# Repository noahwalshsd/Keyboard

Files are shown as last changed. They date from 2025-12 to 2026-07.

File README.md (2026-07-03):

# Slim Shady Keyboard
My project is a 65% orthographic mecanical keyboard. It will be more ergonomic than a regular keyboard and mimic a laptop keyboard in its quietness and lack of push depth. 
I needed to get into PCBs. Before this project, I didn't even know what they were or even what PCB meant. I decided to make an ortholinear keyboardbecause I saw them being priced extremely high and I thought I could make it cheaper as my first PCB project. Because it is my first PCB project, I spent well over the suggested time in my learning efforts. I failed many times in nearly everything. I only got the CAD right first try. The cherry on top is that I may qualify for Prototype. 
There is 1 spacebar keycap, 1 3-wide keycap, 5 2-wide keycaps, and 60 small keycaps. 













BOM: You can find it at the BOM.csv tab






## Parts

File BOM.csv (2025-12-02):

Material | Cost per | Amount needed | Total Cost | Do I have? | HC funding | Link
PCB | $22.40 | 1 | $29.27 | No | $29.27 | https://cart.jlcpcb.com/shopcart/cart, Board: Y2-11347334A
RP Pico | $11.39 | 1 | $11.39 | No | $11.39 | https://www.amazon.com/GATERON-Silent-Keyboard-Switches-Mechanical/dp/B0CPXXRPSQ
PLA Filament | $14 | 1 | $14 | Yes | N/A | https://us.elegoo.com/collections/pla-filament/products/pla-filament-1-75mm-colored-1kg
Gateron KS-9 Switches (35 CT) | $20.15 | 2 | $40.30 | No | $40.30 | https://www.amazon.com/GATERON-Silent-Keyboard-Switches-Mechanical/dp/B0CPXXRPSQ
DO-35 Diodes (125 pc) | $5.99 | 1 | $5.99 | No | $5.99 | https://www.amazon.com/gp/product/B07Q4F3Y5W/ref=ox_sc_act_title_1?smid=A2RFXKS6GNXFWP&psc=1
Total |  |  | $100.95 |  | $86.95

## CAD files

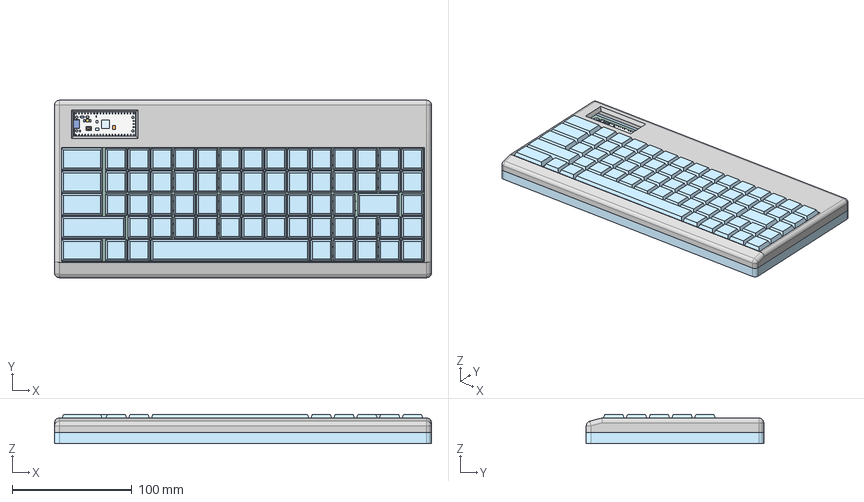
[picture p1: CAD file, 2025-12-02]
CAD.step
315.2 x 148.5 x 24.6 mm
KiCad 1_PCB
?�?__??__��_ x 132
MX? ?�LEDLEDLED x 330
MX ? ??����_���?_ _ x 66
MX �� ������_��_ __��1 x 66
MX�� ���� �ײ� �̡�2 __Ĭ��_��2____��_ x 66
PICO_REF_LED
PICO_REF_INDUCTOR
PICO_REF_COMP_3 x 2
PICO_REF_COMP_1
PICO_REF_COMP_5
PICO_REF_USB x 5
PICO_REF_COMP_6
PICO_REF_COMP_4
PICO_REF_SWITCH
PICO_REF_MICROCONTROLLER
PICO_REF_BOARD
PICO_REF_COMP_2
PICO_REF_COMP_7

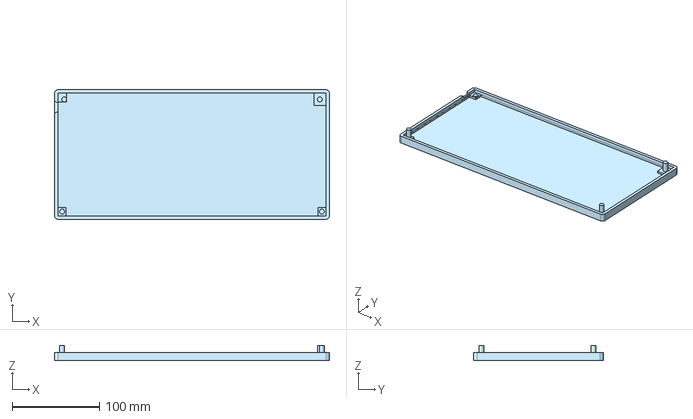
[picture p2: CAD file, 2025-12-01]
Production/CAD pieces/Bottom.step
315.2 x 148.5 x 17.3 mm

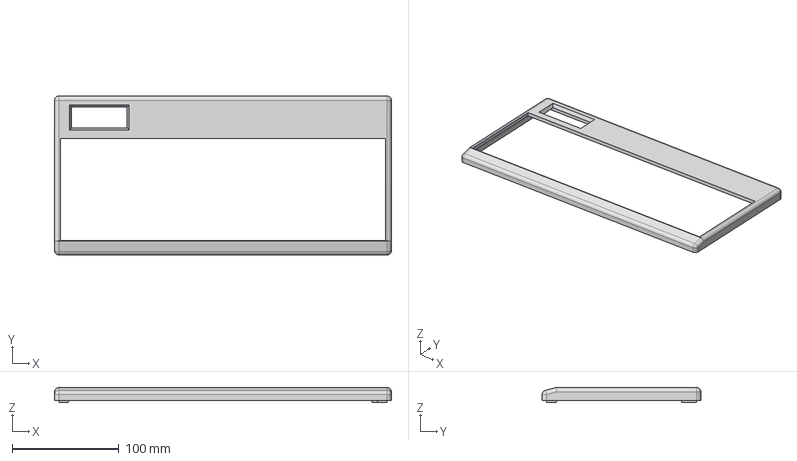
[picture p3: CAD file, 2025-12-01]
Production/CAD pieces/Top.step
315.2 x 148.5 x 14.0 mm

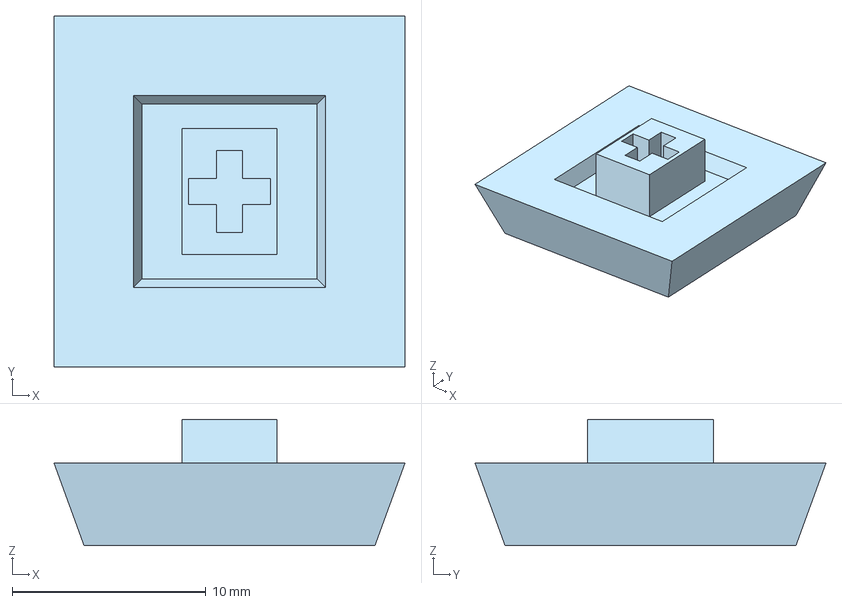
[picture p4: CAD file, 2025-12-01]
Production/CAD pieces/Common Keycap.step
18.1 x 18.1 x 6.50 mm

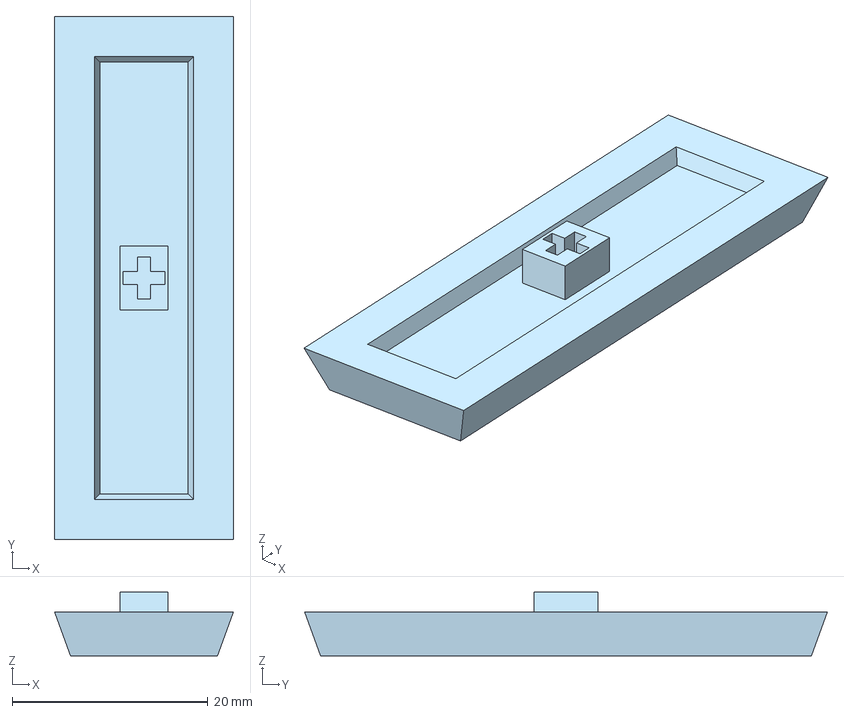
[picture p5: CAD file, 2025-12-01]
Production/CAD pieces/3-wide keyboard.step
18.3 x 53.4 x 6.50 mm

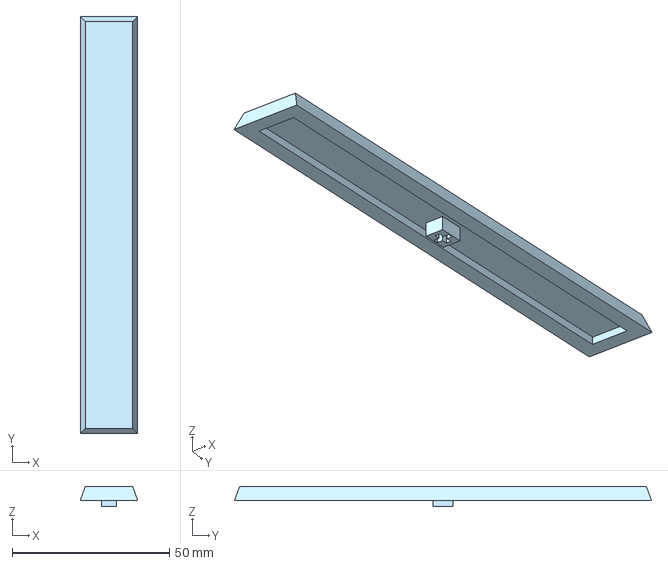
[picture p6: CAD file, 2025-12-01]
Production/CAD pieces/Spacebar keycap.step
18.3 x 132.6 x 6.50 mm

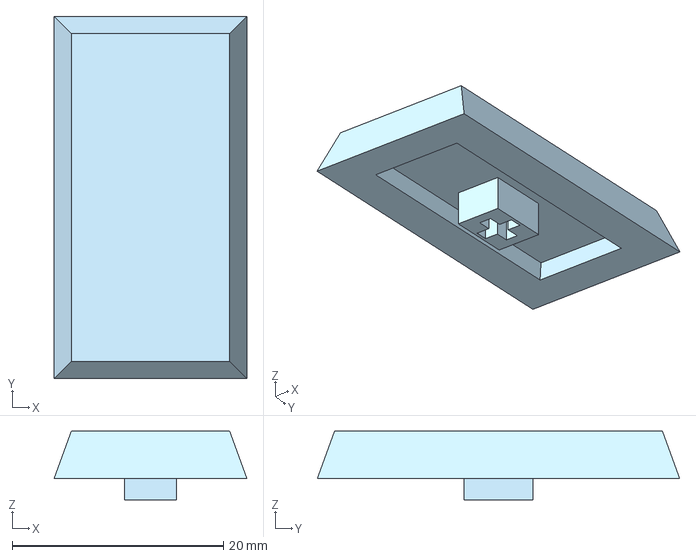
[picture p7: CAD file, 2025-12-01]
Production/CAD pieces/2 wide keycap.step
18.3 x 34.3 x 6.50 mm

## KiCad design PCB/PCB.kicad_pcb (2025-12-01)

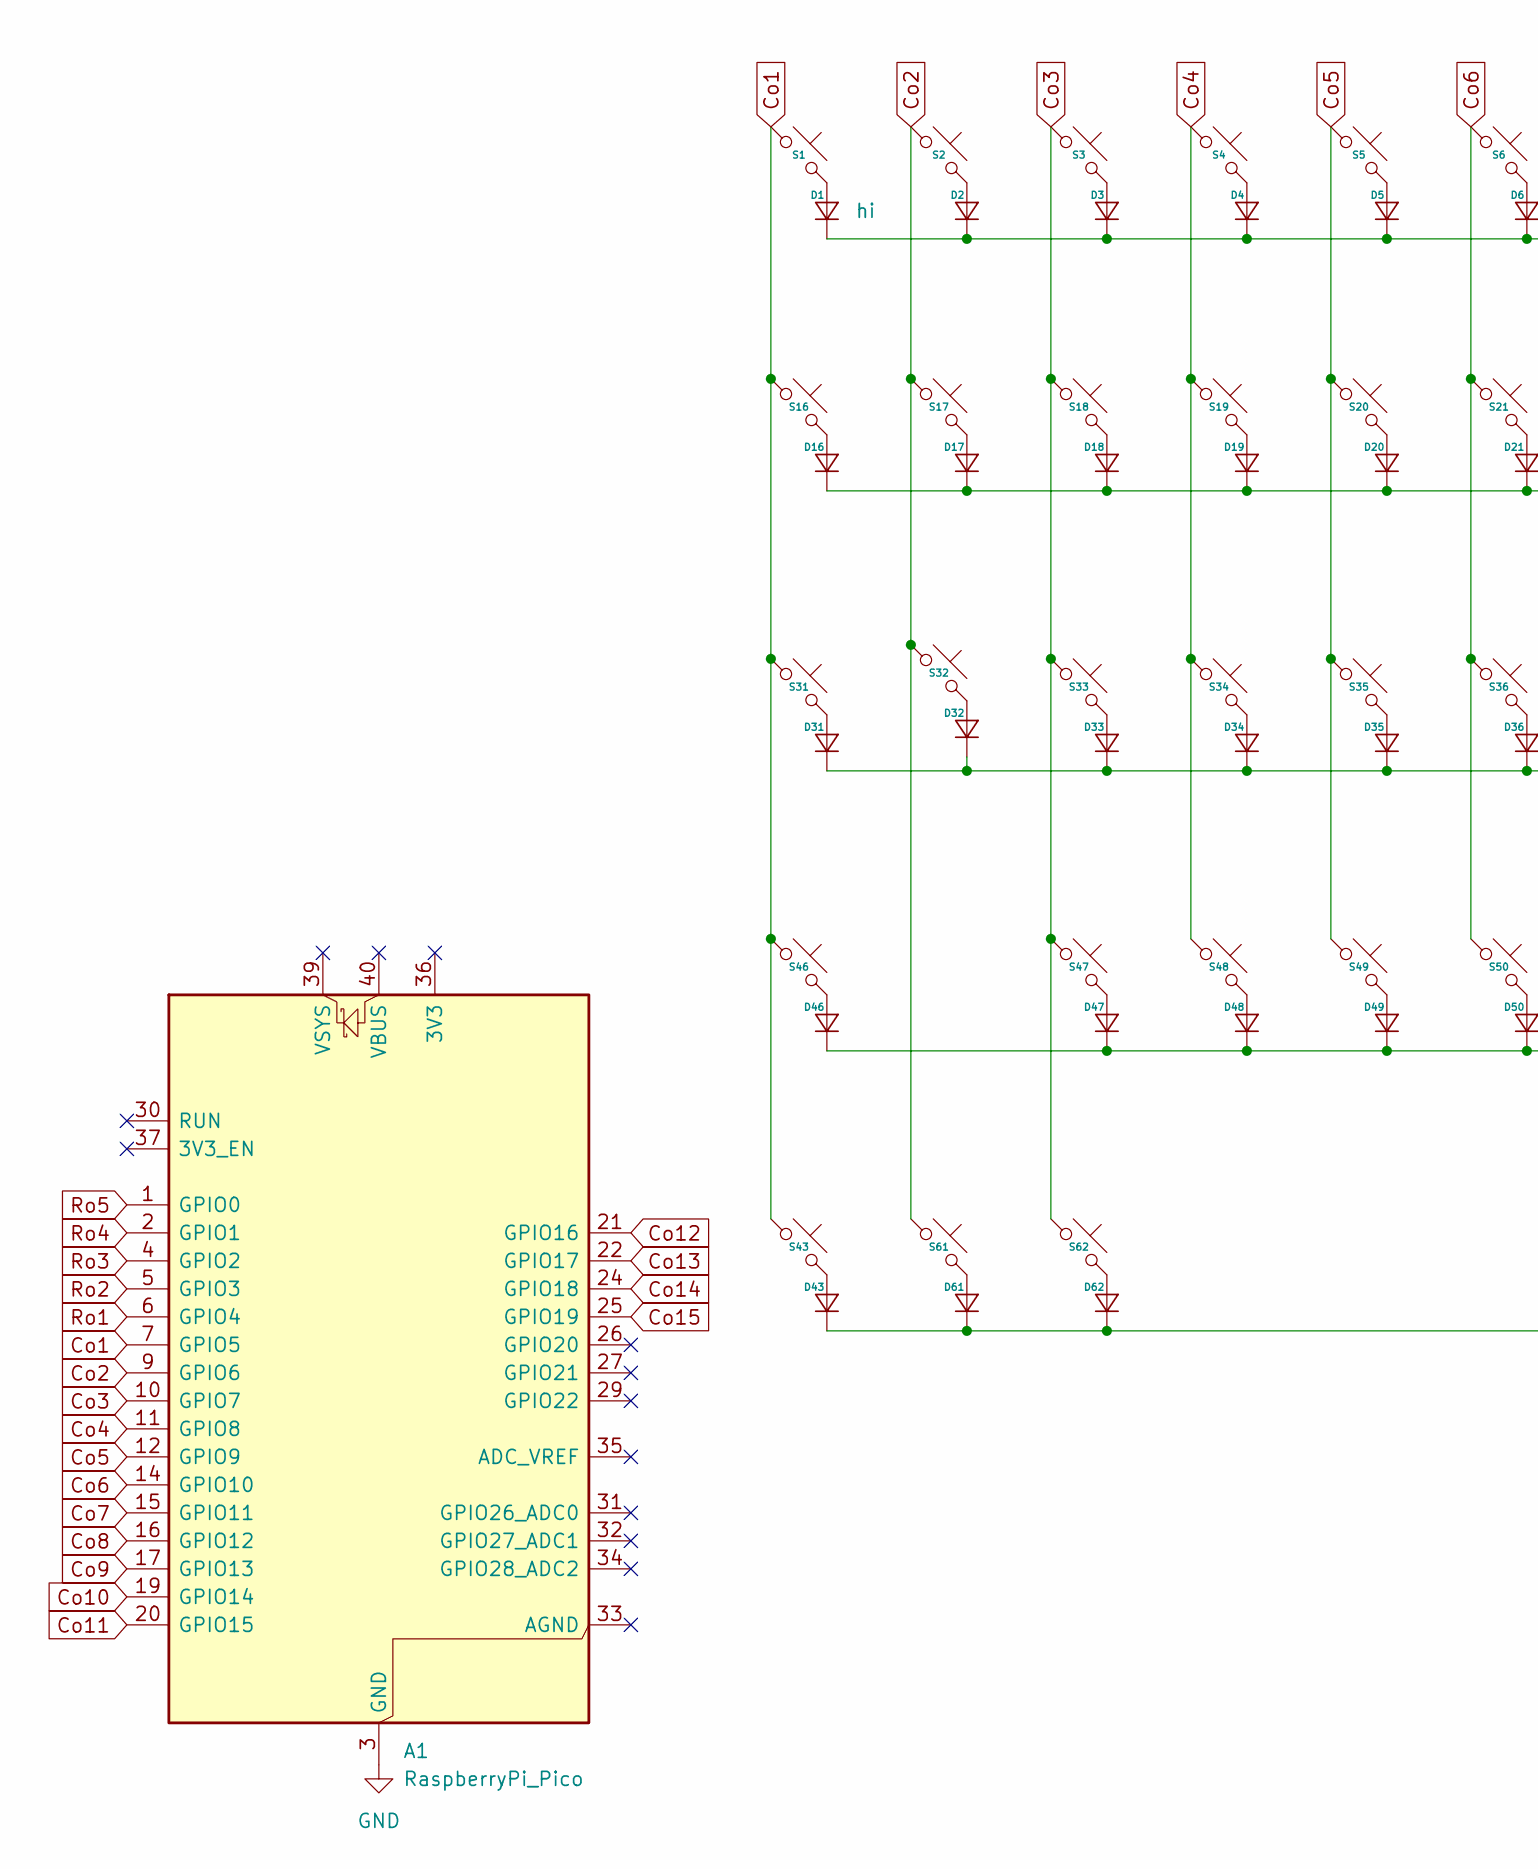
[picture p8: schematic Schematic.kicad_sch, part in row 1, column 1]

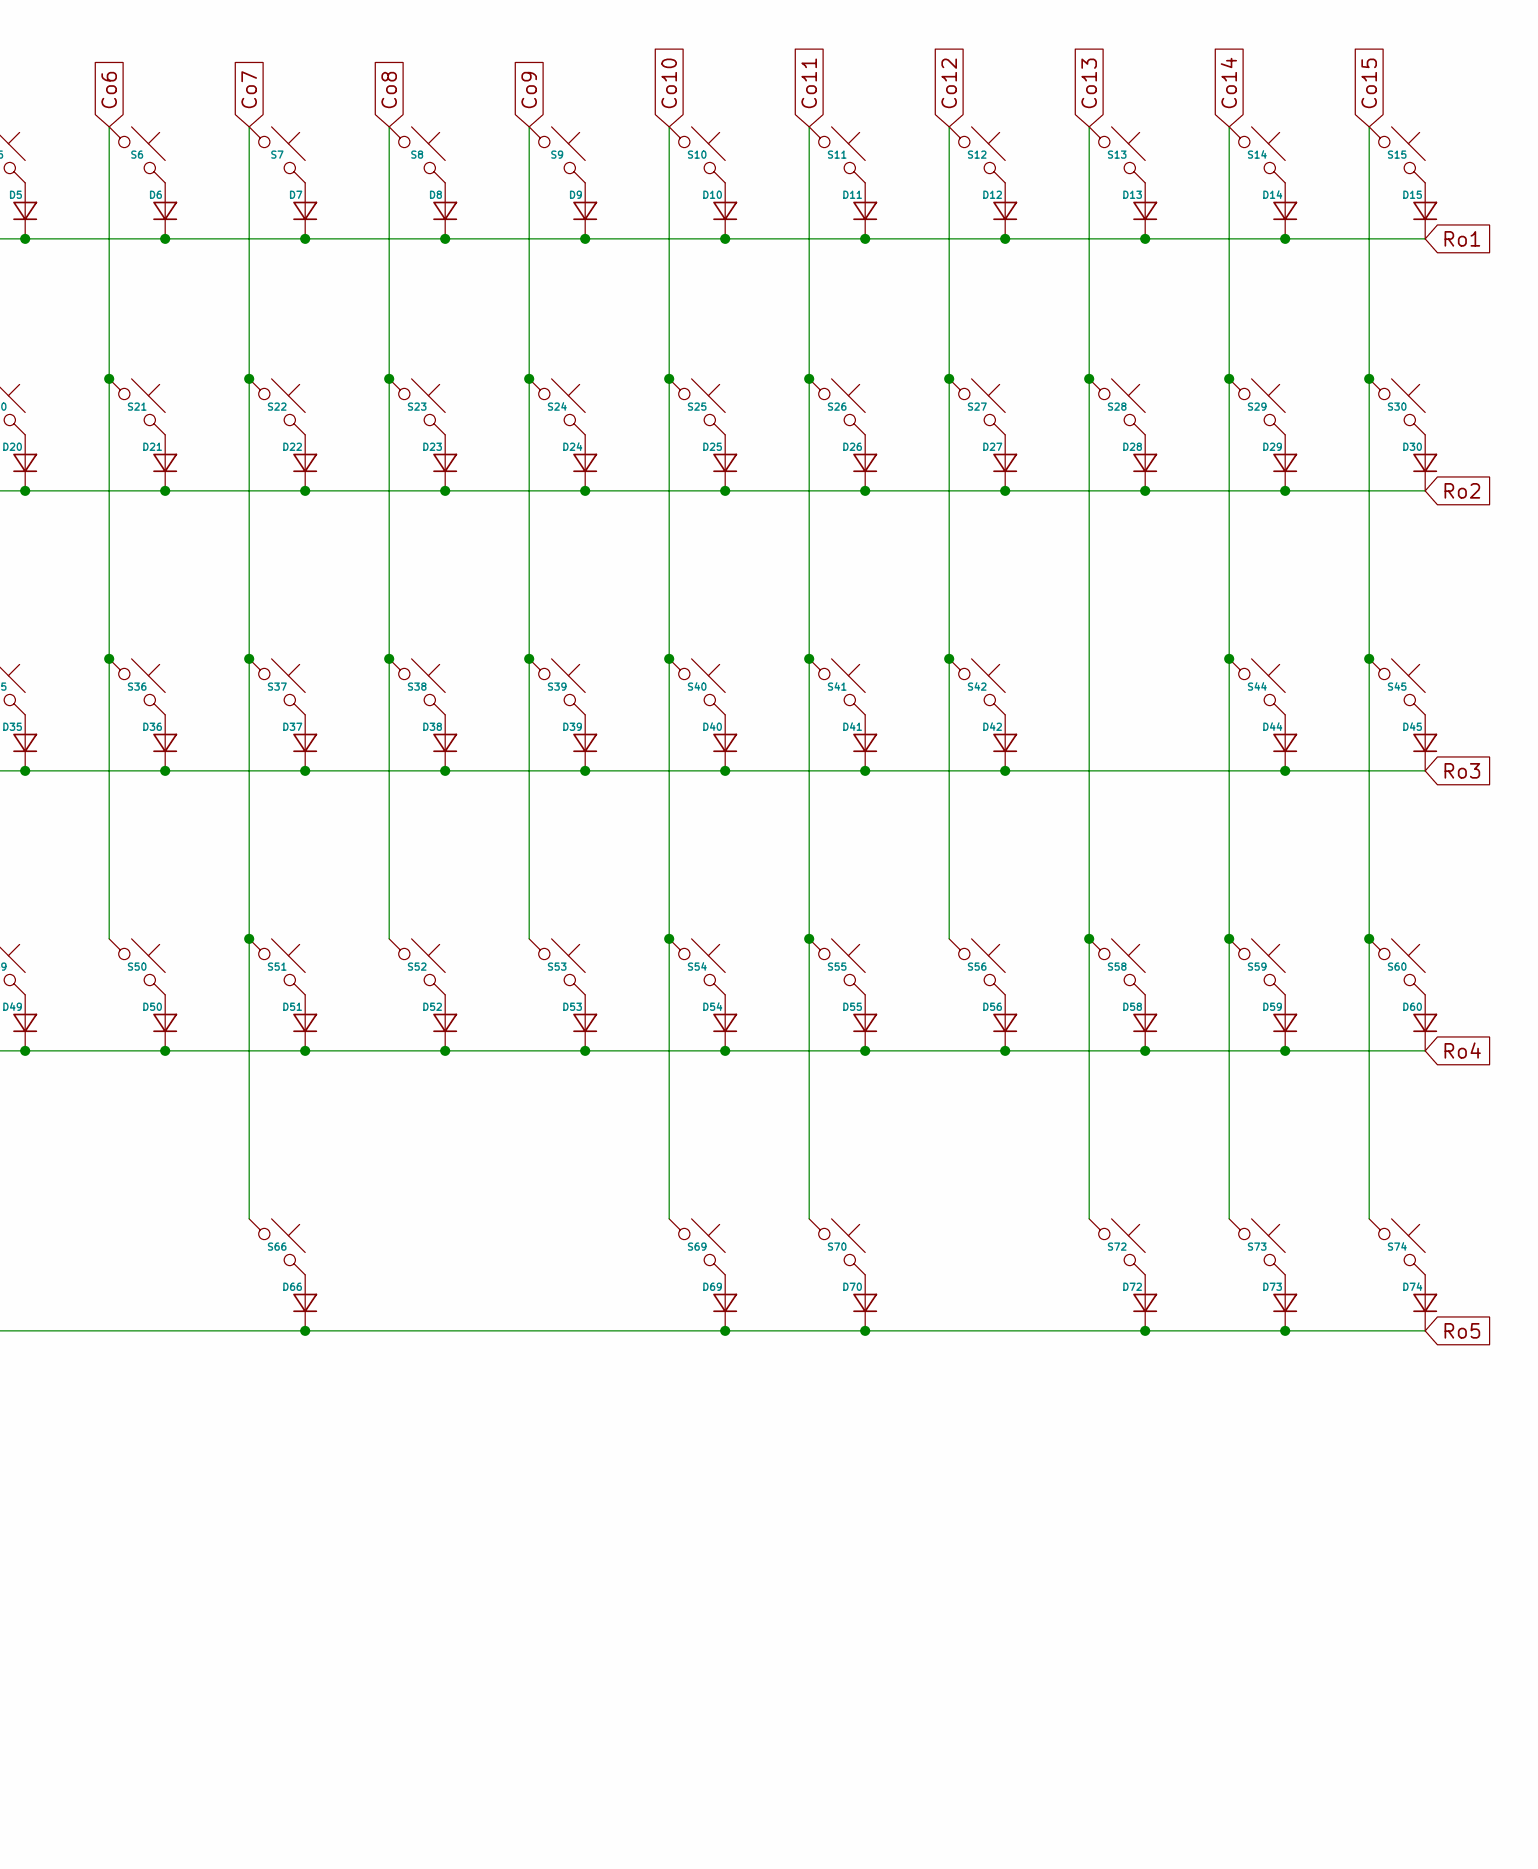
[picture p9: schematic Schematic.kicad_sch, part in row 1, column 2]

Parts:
A1: RaspberryPi_Pico; Raspberry_Pi_Pico
D1: hi; Diode_DO-35
D2, D3, D4, D5, D6, D7, D8, D9, D10, D11, D12, D13, D14, D15, D16, D17, D18, D19, D20, D21, D22, D23, D24, D25, D26, D27, D28, D29, D30, D31, D32, D33, D34, D35, D36, D37, D38, D39, D40, D41, D42, D43, D44, D45, D46, D47, D48, D49, D50, D51, D52, D53, D54, D55, D56, D58, D59, D60, D61, D62, D66, D69, D70, D72, D73, D74: Diode_DO-35
S1, S2, S3, S4, S5, S6, S7, S8, S9, S10, S11, S12, S13, S14, S15, S16, S17, S18, S19, S20, S21, S22, S23, S24, S25, S26, S27, S28, S29, S30, S31, S32, S33, S34, S35, S36, S37, S38, S39, S40, S41, S42, S43, S44, S45, S46, S47, S48, S49, S50, S51, S52, S53, S54, S55, S56, S58, S59, S60, S61, S62, S66, S69, S70, S72, S73, S74: MX_PCB_1.00u

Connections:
Co1: A1.7 (GPIO5), S1.1, S16.1, S31.1, S43.1, S46.1
Co2: A1.9 (GPIO6), S2.1, S17.1, S32.1, S61.1
Co3: A1.10 (GPIO7), S3.1, S18.1, S33.1, S47.1, S62.1
Co4: A1.11 (GPIO8), S4.1, S19.1, S34.1, S48.1
Co5: A1.12 (GPIO9), S5.1, S20.1, S35.1, S49.1
Co6: A1.14 (GPIO10), S6.1, S21.1, S36.1, S50.1
Co7: A1.15 (GPIO11), S7.1, S22.1, S37.1, S51.1, S66.1
Co8: A1.16 (GPIO12), S8.1, S23.1, S38.1, S52.1
Co9: A1.17 (GPIO13), S9.1, S24.1, S39.1, S53.1
Co10: A1.19 (GPIO14), S10.1, S25.1, S40.1, S54.1, S69.1
Co11: A1.20 (GPIO15), S11.1, S26.1, S41.1, S55.1, S70.1
Co12: A1.21 (GPIO16), S12.1, S27.1, S42.1, S56.1
Co13: A1.22 (GPIO17), S13.1, S28.1, S58.1, S72.1
Co14: A1.24 (GPIO18), S14.1, S29.1, S44.1, S59.1, S73.1
Co15: A1.25 (GPIO19), S15.1, S30.1, S45.1, S60.1, S74.1
GND: A1.3 (GND), A1.8 (GND), A1.13 (GND), A1.18 (GND), A1.23 (GND), A1.28 (GND), A1.38 (GND)
unnamed: D1.2 (A), S1.2
unnamed: D2.2 (A), S2.2
unnamed: D3.2 (A), S3.2
unnamed: D4.2 (A), S4.2
unnamed: D5.2 (A), S5.2
unnamed: D6.2 (A), S6.2
unnamed: D7.2 (A), S7.2
unnamed: D8.2 (A), S8.2
unnamed: D9.2 (A), S9.2
unnamed: D10.2 (A), S10.2
unnamed: D11.2 (A), S11.2
unnamed: D12.2 (A), S12.2
unnamed: D13.2 (A), S13.2
unnamed: D14.2 (A), S14.2
unnamed: D15.2 (A), S15.2
unnamed: D16.2 (A), S16.2
unnamed: D17.2 (A), S17.2
unnamed: D18.2 (A), S18.2
unnamed: D19.2 (A), S19.2
unnamed: D20.2 (A), S20.2
unnamed: D21.2 (A), S21.2
unnamed: D22.2 (A), S22.2
unnamed: D23.2 (A), S23.2
unnamed: D24.2 (A), S24.2
unnamed: D25.2 (A), S25.2
unnamed: D26.2 (A), S26.2
unnamed: D27.2 (A), S27.2
unnamed: D28.2 (A), S28.2
unnamed: D29.2 (A), S29.2
unnamed: D30.2 (A), S30.2
unnamed: D31.2 (A), S31.2
unnamed: D32.2 (A), S32.2
unnamed: D33.2 (A), S33.2
unnamed: D34.2 (A), S34.2
unnamed: D35.2 (A), S35.2
unnamed: D36.2 (A), S36.2
unnamed: D37.2 (A), S37.2
unnamed: D38.2 (A), S38.2
unnamed: D39.2 (A), S39.2
unnamed: D40.2 (A), S40.2
unnamed: D41.2 (A), S41.2
unnamed: D42.2 (A), S42.2
unnamed: D43.2 (A), S43.2
unnamed: D44.2 (A), S44.2
unnamed: D45.2 (A), S45.2
unnamed: D46.2 (A), S46.2
unnamed: D47.2 (A), S47.2
unnamed: D48.2 (A), S48.2
unnamed: D49.2 (A), S49.2
unnamed: D50.2 (A), S50.2
unnamed: D51.2 (A), S51.2
unnamed: D52.2 (A), S52.2
unnamed: D53.2 (A), S53.2
unnamed: D54.2 (A), S54.2
unnamed: D55.2 (A), S55.2
unnamed: D56.2 (A), S56.2
unnamed: D58.2 (A), S58.2
unnamed: D59.2 (A), S59.2
unnamed: D60.2 (A), S60.2
unnamed: D61.2 (A), S61.2
unnamed: D62.2 (A), S62.2
unnamed: D66.2 (A), S66.2
unnamed: D69.2 (A), S69.2
unnamed: D70.2 (A), S70.2
unnamed: D72.2 (A), S72.2
unnamed: D73.2 (A), S73.2
unnamed: D74.2 (A), S74.2
Ro1: A1.6 (GPIO4), D1.1 (K), D2.1 (K), D3.1 (K), D4.1 (K), D5.1 (K), D6.1 (K), D7.1 (K), D8.1 (K), D9.1 (K), D10.1 (K), D11.1 (K), D12.1 (K), D13.1 (K), D14.1 (K), D15.1 (K)
Ro2: A1.5 (GPIO3), D16.1 (K), D17.1 (K), D18.1 (K), D19.1 (K), D20.1 (K), D21.1 (K), D22.1 (K), D23.1 (K), D24.1 (K), D25.1 (K), D26.1 (K), D27.1 (K), D28.1 (K), D29.1 (K), D30.1 (K)
Ro3: A1.4 (GPIO2), D31.1 (K), D32.1 (K), D33.1 (K), D34.1 (K), D35.1 (K), D36.1 (K), D37.1 (K), D38.1 (K), D39.1 (K), D40.1 (K), D41.1 (K), D42.1 (K), D44.1 (K), D45.1 (K)
Ro4: A1.2 (GPIO1), D46.1 (K), D47.1 (K), D48.1 (K), D49.1 (K), D50.1 (K), D51.1 (K), D52.1 (K), D53.1 (K), D54.1 (K), D55.1 (K), D56.1 (K), D58.1 (K), D59.1 (K), D60.1 (K)
Ro5: A1.1 (GPIO0), D43.1 (K), D61.1 (K), D62.1 (K), D66.1 (K), D69.1 (K), D70.1 (K), D72.1 (K), D73.1 (K), D74.1 (K)

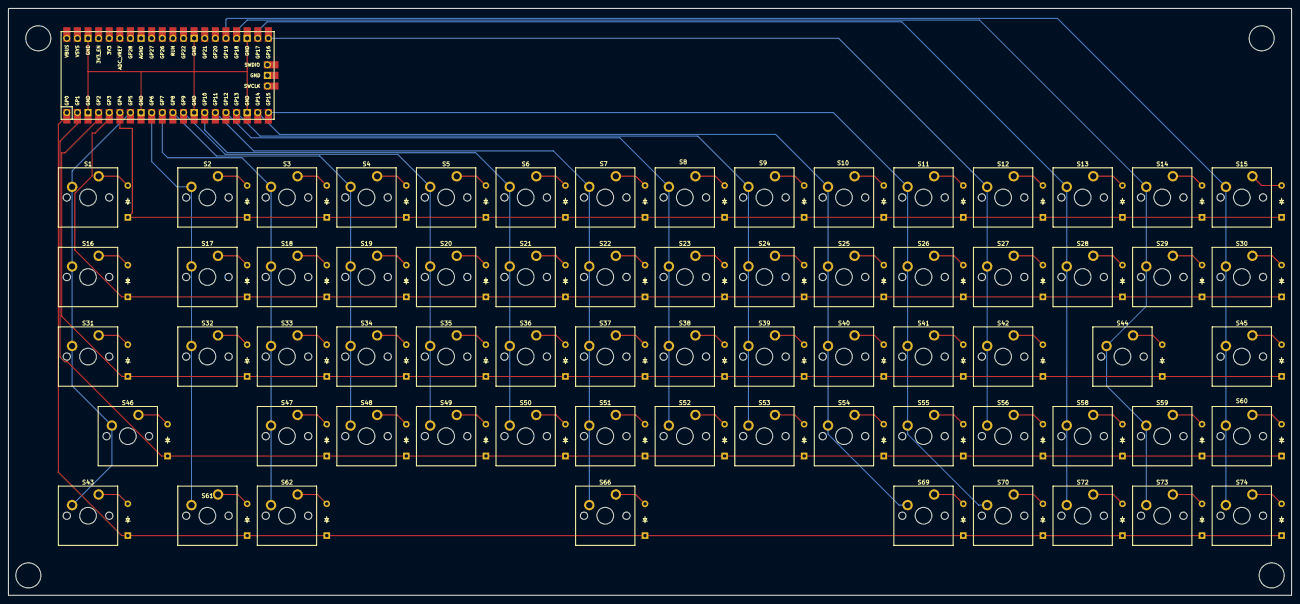
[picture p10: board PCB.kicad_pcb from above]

Board: 2 copper layers, 307.2 x 140.5 mm, 135 parts (0 on the bottom side), 88 nets.

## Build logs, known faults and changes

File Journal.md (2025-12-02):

Total time spent on the project: 18hr
11/21-28/25 - 4hr (research and learning, not counted towart total time)
11/29/25 - 9hr
11/30/25 - 9hr
12/1/25 - 1.5hr

11/29: 



11/30:











12/1/25





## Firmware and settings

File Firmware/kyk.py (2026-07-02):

import board
from kmk.kmk_keyboard import KMKKeyboard
from kmk.scanners import DiodeOrientation
from kmk.keys import KC
from kmk.modules.macros import Macros

keyboard = KMKKeyboard()
macros = Macros()
keyboard.modules.append(macros)

# Define your rows and columns directly
keyboard.row_pins = (board.GP4, board.GP3, board.GP2, board.GP1, board.GP0)
keyboard.col_pins = (board.GP5, board.GP6, board.GP7, board.GP8, board.GP9, board.GP10, board.GP11, board.GP12, board.GP13, board.GP14, board.GP15, board.GP16, board.GP17, board.GP18, board.GP19)
keyboard.diode_orientation = DiodeOrientation.COL2ROW

# One single flat list for Layer 0
keyboard.keymap = [
    [
        # Row 1
        KC.ESC, KC.N1, KC.N2, KC.N3, KC.N4, KC.N5, KC.N6, KC.N7, KC.N8, KC.N9, KC.N0, KC.MINUS, KC.EQUAL, KC.BSPC, KC.HOME,
        # Row 2
        KC.TAB, KC.Q, KC.W, KC.E, KC.R, KC.T, KC.Y, KC.U, KC.I, KC.O, KC.P, KC.LBRC, KC.RBRC, KC.BSLASH, KC.DELETE,
        # Row 3
        KC.CAPSLOCK, KC.A, KC.S, KC.D, KC.F, KC.G, KC.H, KC.J, KC.K, KC.L, KC.SCOLON, KC.QUOTE, KC.ENTER, KC.END, KC.PGUP,
        # Row 4
        KC.LSHIFT, KC.NO, KC.Z, KC.X, KC.C, KC.V, KC.B, KC.N, KC.M, KC.COMMA, KC.DOT, KC.SLASH, KC.RSHIFT, KC.UP, KC.PGDOWN,
        # Row 5
        KC.LCTRL, KC.LGUI, KC.LALT, KC.NO, KC.NO, KC.NO, KC.SPACE, KC.NO, KC.NO, KC.RALT, KC.RGUI, KC.NO, KC.LEFT, KC.DOWN, KC.RIGHT,
    ]
]

keyboard.go()

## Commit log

2025-12-01 Everything
    Expanded project description and added BOM details with costs and links.
2025-12-02 Update images and BOM details in README
    Replaced two images and added a new BOM entry with costs and links.
2025-12-02 Revise BOM section in README.md
    Updated the Bill of Materials (BOM) section with new items and corrected formatting.
2025-12-02 Fix BOM.csv formatting and header alignment
    [BOM.csv]
2025-12-02 Update BOM.csv with new format and data
    [BOM.csv]
2025-12-02 Remove items from BOM in README
    Removed several items from the BOM section in the README.
2025-12-02 Update README with BOM location information
    Added a note about the BOM location in the README.
